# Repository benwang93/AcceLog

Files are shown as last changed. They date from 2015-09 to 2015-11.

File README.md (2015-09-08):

AcceLog - Accelerometer Log for Android
=======================================

Android
-------
This project uses the Adafruit MMA8451 breakout board connected to an Arduino Uno. The sensor and Arduino hardware can be easily modified. Eventually a custom board and enclosure should be built.

Links:
- Adafruit MMA8451 webpage:    adafru.it/2019
- Adafruit Arduino libraries:  https://learn.adafruit.com/adafruit-mma8451-accelerometer-breakout/wiring-and-test

The Arduino code and libraries are included in the Arduino folder in this repository.

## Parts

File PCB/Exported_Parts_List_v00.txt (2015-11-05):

Partlist

Exported from AcceLog_v01.sch at 11/5/2015 2:57 PM

EAGLE Version 7.3.0 Copyright (c) 1988-2015 CadSoft

Assembly variant: 

Part     Value           Device                 Package      Library             Sheet

C1       0.1uF           CAP0603-CAP            0603-CAP     SparkFun-Passives   1
C2       2.2uF           CAP_POL1206            EIA3216      SparkFun-Capacitors 1
C3       0.1uF           CAP0603-CAP            0603-CAP     SparkFun-Passives   1
C4       0.1uF           CAP0603-CAP            0603-CAP     SparkFun-Passives   1
C5       4.7uF           CAP0603-CAP            0603-CAP     SparkFun-Passives   1
C6       47pF            CAP0603-CAP            0603-CAP     SparkFun-Passives   1
C7       47pF            CAP0603-CAP            0603-CAP     SparkFun-Passives   1
C8       100nF           CAP0603-CAP            0603-CAP     SparkFun-Passives   1
C9       0.1uF           CAP0603-CAP            0603-CAP     SparkFun-Passives   1
C10      18pF            CAP0603-CAP            0603-CAP     SparkFun-Passives   1
C11      18pF            CAP0603-CAP            0603-CAP     SparkFun-Passives   1
C12      0.1uF           CAP0603-CAP            0603-CAP     SparkFun-Passives   1
C13                      CPOL-USE2-5            E2-5         rcl                 1
C15                      CPOL-USE2-5            E2-5         rcl                 1
C16                      CPOL-USE2-5            E2-5         rcl                 1
C17      0.1uF           CAP0603-CAP            0603-CAP     SparkFun-Passives   1
ICSP                     M03X22X3_SILK_MALE_PTH 2X3          SparkFun-Connectors 1
JACCEL                   M08LOCK                1X08_LOCK    SparkFun-Connectors 1
JFTDI                    M06LOCK                1X06_LOCK    SparkFun-Connectors 1
JUSB     10118193        10118193               10118193     MicroUSB            1
R1       27?             RESISTOR0603-RES       0603-RES     SparkFun-Passives   1
R2       27?             RESISTOR0603-RES       0603-RES     SparkFun-Passives   1
R3       27?             RESISTOR0603-RES       0603-RES     SparkFun-Passives   1
R4       10K?            RESISTOR0603-RES       0603-RES     SparkFun-Passives   1
R5       10K?            RESISTOR0603-RES       0603-RES     SparkFun-Passives   1
U1       MMA8452Q        MMA8452Q               QFN-16_0.5MM SparkFun-Sensors    1
U2       FTS31XS-U       FT231XS                SSOP20_L     SparkFun-DigitalIC  1
U3       ATMEGA328P_TQFP ATMEGA328P_TQFP        TQFP32-08    SparkFun-DigitalIC  1
U4       3.3V/150mA      V_REG_MIC52053.3V      SOT23-5      SparkFun-PowerIC    1
XTAL     ABLS7M2         ABLS7M2                ABLS7M2      AcceLogLib          1

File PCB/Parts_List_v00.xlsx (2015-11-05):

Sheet: Parts List
Component | Use | Description | Digikey part | Quantity | Qty Order | Price | Link
Processor | x | Atmega328P | ATMEGA328P-AU-ND | 1 | 3 | $3.58 | http://www.digikey.com/product-detail/en/ATMEGA328P-AU/ATMEGA328P-AU-ND/1832260
Oscillator | x | Small crystal | 535-12830-1-ND | 1 | 4 | $0.38 | http://www.digikey.com/product-detail/en/ABLS7M2-16.000MHZ-D-2Y-T/535-12830-1-ND/5135076
Oscillator |  | Crystal search page |  |  |  |  | http://www.digikey.com/product-search/en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
Oscillator |  | Big crystal | 535-10226-1-ND |  |  | $0.27 | http://www.digikey.com/product-detail/en/ABLS-16.000MHZ-B4-T/535-10226-1-ND/2184261
Oscillator |  | Resonator | 535-10008-1-ND |  |  | $0.38 | http://www.digikey.com/product-detail/en/AWSCR-16.00CV-T/535-10008-1-ND/2001631
Oscillator |  | MEMS oscillator | 336-2902-ND |  |  | $0.96 | http://www.digikey.com/product-detail/en/501BAA16M0000DAF/336-2902-ND/4582012
MicroUSB | x | MicroUSB jack | 609-4616-1-ND | 1 | 4 | $0.46 | http://www.digikey.com/product-detail/en/10118193-0001LF/609-4616-1-ND/2785380
Cap 0603 | x | 0.1uF | 399-1096-1-ND | 7 | 25 | $0.10 | http://www.digikey.com/product-detail/en/C0603C104K4RACTU/399-1096-1-ND/411371
Cap 0603 | x | 4.7uF | 1276-2087-1-ND | 1 | 5 | $0.10 | http://www.digikey.com/product-detail/en/CL10B475KQ8NQNC/1276-2087-1-ND/3890173
Cap 0603 | x | 47pF | 399-9083-1-ND | 2 | 10 | $0.10 | http://www.digikey.com/product-detail/en/C0603C470J3GACTU/399-9083-1-ND/3522600
Cap 0603 | x | 18pF | 399-1052-1-ND | 2 | 10 | $0.10 | http://www.digikey.com/product-detail/en/C0603C180J5GACTU/399-1052-1-ND/411327
Cap 1206 | x | 2.2uF Tantalum | 495-2228-1-ND | 1 | 5 | $0.33 | http://www.digikey.com/product-detail/en/T491A225K016ZT/495-2228-1-ND/770394
Cap 5mm | x
2x3 male hdr | x | 6 pos 2 row | 952-2121-ND | 1 | 4 | $0.23
male hdr | x | 40 pin breakaway | S1012EC-40-ND | 1 | 5 | $0.56 | http://www.digikey.com/product-detail/en/PREC040SAAN-RC/S1012EC-40-ND/2774814
male ang hdr | x | 40 pin breakaway | S1112EC-40-ND | 1 | 3 | $0.74 | http://www.digikey.com/product-detail/en/PREC040SBAN-M71RC/S1112EC-40-ND/2774894
Res 0603 | x | 27 Ohm | 311-27GRCT-ND | 3 | 15 | $0.01 | http://www.digikey.com/product-detail/en/RC0603JR-0727RL/311-27GRCT-ND/729698
Res 0603 | x | 10 kOhm | 311-10KGRCT-ND | 2 | 10 | $0.01 | http://www.digikey.com/product-detail/en/RC0603JR-0710KL/311-10KGRCT-ND/729647
Accelerometer | x | MMA8452Q | MMA8451QR1CT-ND | 1 | 3 | $1.82 | http://www.digikey.com/product-detail/en/MMA8451QR1/MMA8451QR1CT-ND/3524270
FTDI | x | FTS31XS-U | 768-1156-5-ND | 1 | 3 | $2.12 | http://www.digikey.com/product-detail/en/FT231XS-U/768-1156-5-ND/3749471
Voltage Reg | x | 3.3V/150mA | 296-35591-1-ND | 1 | 4 | $0.49 | http://www.digikey.com/product-detail/en/TLV71333PDBVR/296-35591-1-ND/3830056

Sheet: EAGLE Export
Part | Value | Device | Package | Library | Sheet
C1 | 0.1uF | CAP0603-CAP | 0603-CAP | SparkFun-Passives
C2 | 2.2uF | CAP_POL1206 | EIA3216 | SparkFun-Capacitors 1
C3 | 0.1uF | CAP0603-CAP | 0603-CAP | SparkFun-Passives 1
C4 | 100nF | CAP0603-CAP | 0603-CAP | SparkFun-Passives 1
C5 | 4.7uF | CAP0603-CAP | 0603-CAP | SparkFun-Passives 1
C6 | 47pF | CAP0603-CAP | 0603-CAP | SparkFun-Passives 1
C7 | 47pF | CAP0603-CAP | 0603-CAP | SparkFun-Passives 1
C8 | 100nF | CAP0603-CAP | 0603-CAP | SparkFun-Passives 1
C9 | 0.1uF | CAP0603-CAP | 0603-CAP | SparkFun-Passives 1
C10 | 18pF | CAP0603-CAP | 0603-CAP | SparkFun-Passives 1
C11 | 18pF | CAP0603-CAP | 0603-CAP | SparkFun-Passives 1
C12 | 100nF | CAP0603-CAP | 0603-CAP | SparkFun-Passives 1
C13 |  | CPOL-USE2-5 | E2-5 | rcl | 1
C14 |  | CPOL-USE2-5 | E2-5 | rcl | 1
C15 |  | CPOL-USE2-5 | E2-5 | rcl | 1
C16 |  | CPOL-USE2-5 | E2-5 | rcl | 1
C17 | 100nF | CAP0603-CAP | 0603-CAP | SparkFun-Passives 1
ICSP |  | M03X22X3_SILK_MALE_PTH | 2X3 | SparkFun-Connectors 1
JACCEL |  | M08LOCK | 1X08_LOCK | SparkFun-Connectors 1
JFTDI |  | M06LOCK | 1X06_LOCK | SparkFun-Connectors 1
JUSB | 10118193 | 10118193 | 10118193 | MicroUSB | 1
R1 | 27? | RESISTOR0603-RES | 0603-RES | SparkFun-Passives 1
R2 | 27? | RESISTOR0603-RES | 0603-RES | SparkFun-Passives 1
R3 | 27? | RESISTOR0603-RES | 0603-RES | SparkFun-Passives 1
R4 | 10K? | RESISTOR0603-RES | 0603-RES | SparkFun-Passives 1
R5 | 10K? | RESISTOR0603-RES | 0603-RES | SparkFun-Passives 1
U1 | MMA8452Q | MMA8452Q | QFN-16_0.5MM SparkFun-Sensors | 1
U2 | FTS31XS-U | FT231XS | SSOP20_L | SparkFun-DigitalIC 1
U3 | ATMEGA328P_TQFP | ATMEGA328P_TQFP | TQFP32-08 | SparkFun-DigitalIC 1
U4 | 3.3V/150mA | V_REG_MIC52053.3V | SOT23-5 | SparkFun-PowerIC | 1
XTAL | ABLS7M2 | ABLS7M2 | ABLS7M2 | AcceLogLib | 1

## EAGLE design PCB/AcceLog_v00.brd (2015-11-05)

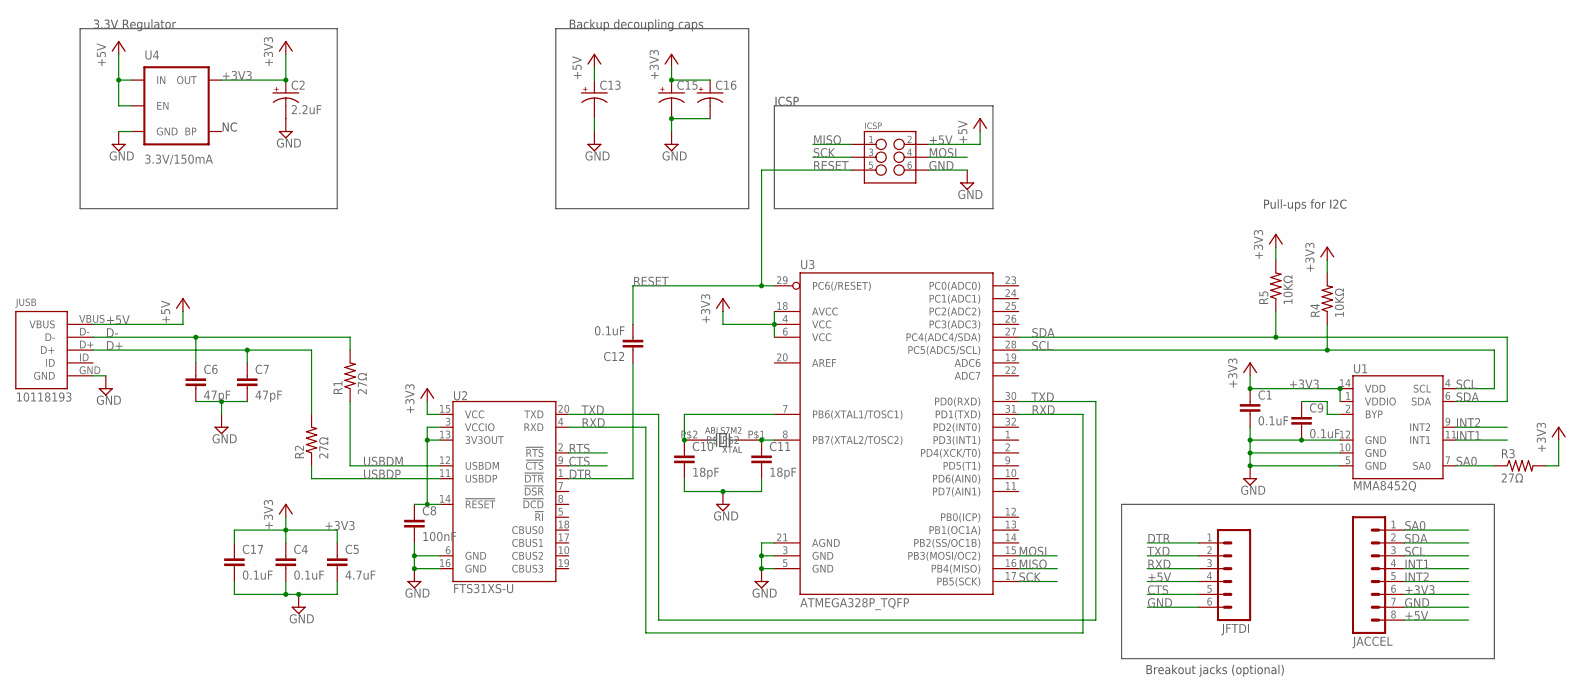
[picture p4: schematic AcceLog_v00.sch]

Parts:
C1, C4, C9, C12, C17: 0.1uF; 0603-CAP
C2: 2.2uF; EIA3216
C5: 4.7uF; 0603-CAP
C6, C7: 47pF; 0603-CAP
C8: 100nF; 0603-CAP
C10, C11: 18pF; 0603-CAP
C13, C15, C16: CPOL-USE2-5; E2-5
ICSP: M03X22X3_SILK_MALE_PTH; 2X3
JACCEL: M08LOCK; 1X08_LOCK
JFTDI: M06LOCK; 1X06_LOCK
JUSB: 10118193
R1, R2, R3: 27Ω; 0603-RES
R4, R5: 10KΩ; 0603-RES
U1: MMA8452Q; QFN-16_0.5MM
U2: FTS31XS-U; SSOP20_L
U3: ATMEGA328P_TQFP; TQFP32-08
U4: 3.3V/150mA; SOT23-5
XTAL: ABLS7M2

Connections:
+3V3: C1.1, C2.A (+), C4.1, C5.1, C15.+, C16.+, C17.1, JACCEL.6, R3.2, R4.2, R5.2, U1.1 (VDDIO), U1.14 (VDD), U2.15 (VCC), U3.4 (VCC), U3.6 (VCC), U3.18 (AVCC), U4.5 (OUT)
+5V: C13.+, ICSP.2, JACCEL.8, JFTDI.4, JUSB.VBUS, U4.1 (IN), U4.3 (EN)
CTS: JFTDI.5, U2.9 (!CTS)
D+: C7.1, JUSB.D+, R2.2
D-: C6.1, JUSB.D-, R1.2
DTR: C12.1, JFTDI.1, U2.1 (!DTR)
FTDI3V3: C8.1, U2.3 (VCCIO), U2.13 (3V3OUT), U2.14 (!RESET)
GND: C1.2, C2.C (-), C4.2, C5.2, C6.2, C7.2, C8.2, C9.2, C10.2, C11.2, C13.-, C15.-, C16.-, C17.2, ICSP.6, JACCEL.7, JFTDI.6, JUSB.GND, U1.5 (GND), U1.10 (GND), U1.12 (GND), U2.6 (GND), U2.16 (GND), U3.3 (GND), U3.5 (GND), U3.21 (AGND), U4.2 (GND)
INT1: JACCEL.4, U1.11 (INT1)
INT2: JACCEL.5, U1.9 (INT2)
MISO: ICSP.1, U3.16 (PB4(MISO))
MOSI: ICSP.4, U3.15 (PB3(MOSI/OC2))
unnamed: C10.1, U3.7 (PB6(XTAL1/TOSC1)), XTAL.P$2
unnamed: C9.1, U1.2 (BYP)
unnamed: C11.1, U3.8 (PB7(XTAL2/TOSC2)), XTAL.P$1
RESET: C12.2, ICSP.5, U3.29 (PC6(/RESET))
RTS: U2.2 (!RTS)
RXD: JFTDI.3, U2.4 (RXD), U3.31 (PD1(TXD))
SA0: JACCEL.1, R3.1, U1.7 (SA0)
SCK: ICSP.3, U3.17 (PB5(SCK))
SCL: JACCEL.3, R4.1, U1.4 (SCL), U3.28 (PC5(ADC5/SCL))
SDA: JACCEL.2, R5.1, U1.6 (SDA), U3.27 (PC4(ADC4/SDA))
TXD: JFTDI.2, U2.20 (TXD), U3.30 (PD0(RXD))
USBDM: R1.1, U2.12 (USBDM)
USBDP: R2.1, U2.11 (USBDP)

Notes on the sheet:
3.3V Regulator
Pull-ups for I2C
ICSP
Backup decoupling caps
Breakout jacks (optional)

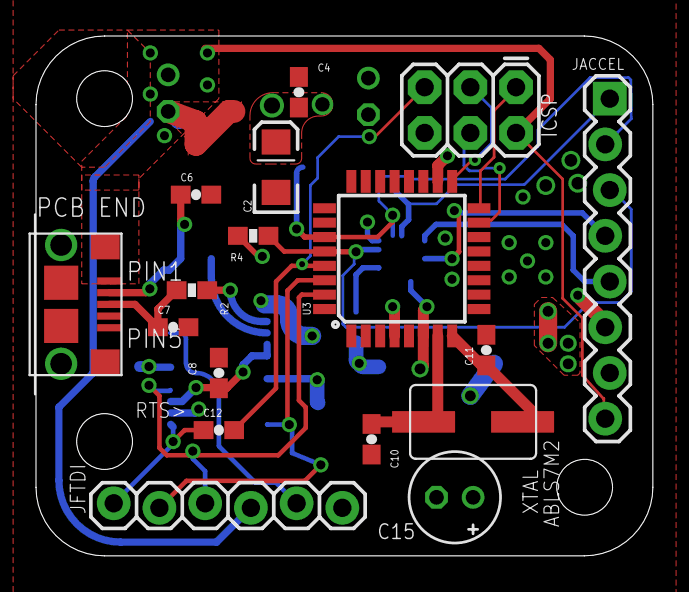
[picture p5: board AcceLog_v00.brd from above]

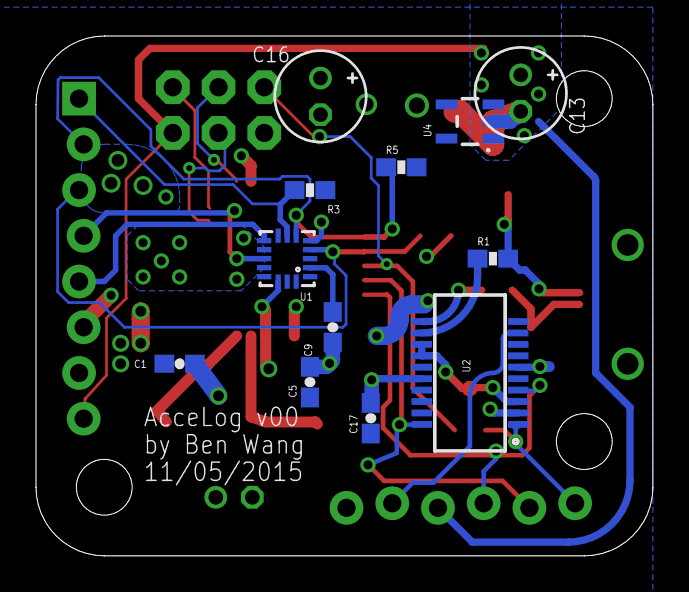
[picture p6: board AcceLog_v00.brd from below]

Board: 2 copper layers, 34.3 x 28.9 mm, 29 parts (12 on the bottom side), 24 nets.

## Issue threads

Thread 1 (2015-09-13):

Increase baud rate from 9600 to 115200

benwang93, 2015-09-13:

benwang93, 2015-09-17:
Found out that the getLineEncoding() function in AndroidSerialMonitor just sends the baud rate encoded as hex to the Arduino pseudo-FTDI. Upped the baud rate to 115200, but now phone crashes very quickly. Decreased it to 19200, but it still crashes quick.

Determined the app is not crashing from the graph by plotting only 1/100 data points

benwang93, 2015-09-24:
After implementing delete on old points (>120 points) on graph, app runs longer now.

115200 is a bit high with the current scheme - app crashes within a minute. At least need to improve data efficiency.

19200 works well, at least for 10+ minutes.

benwang93, 2015-10-02:
Implemented new serial packet structure, where binary data is now sent in the form of:
  [SOP][time in millis (int)][accel x (float)][accel y (float)][accel z (float)]

This takes 6.25ms to send 1 packet (15*(1/19200)*1000*8)ms, and we are getting ~9ms between samples. Arduino is programmed with a 100us delay between each packet.

Next: Try increasing baud rate to 115200. Should yield a theoretical data transfer time of (15*(1/115200)*1000*8) = 1.0416666666667ms

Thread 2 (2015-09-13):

App crashes within the first few seconds of starting logging

benwang93, 2015-09-13:
This may be associated with the console. Perhaps start by trying to disable the console prints

benwang93, 2015-10-02:
Added exception checking. Error was with incorrectly parsed packet. Newest implementation doesn't support old string packet structure/parsing anyway.

Closed 2015-10-02.

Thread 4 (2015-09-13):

Endurance test

benwang93, 2015-09-13:
Investigate effects on app speed over time.

1. Start with disabling console print
2. Try saving in background task to not slow down UI thread
3. If still slow, try saving periodically and clearing data from memory in background task. Maybe have 2 arrays, and swap/save them every so often

benwang93, 2015-09-13:
If chart is bogging down, can just plot a few times per second, or delete points older than a certain amount of time

benwang93, 2015-09-15:
Status improved by not logging data in console. After rooting phone, able to identify runtime errors. One instance is a malformed double. Try using a try-catch

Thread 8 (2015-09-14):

Notification center & Serial Monitor mode

benwang93, 2015-09-14:
Add textview or scrolling listview at top set to wrap_content layout_height, and add notifications there, with a task scheduled several seconds after to delete them.

The present serial monitor can be hidden until enabled, for debug mode. Don't print to it unless active, to prevent memory from clogging up.

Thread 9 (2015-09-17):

PCB Design

benwang93, 2015-09-17:
1) Spec major components (proc, FTDI, accelerometer)
2) Spec support components (passives/oscillator, voltage regulator?)
3) Schematic
4) PCB v0
5) Order parts

benwang93, 2015-10-02:
Case idea: (laser) cut 2 acryllic panels, sandwich PCB w/ spacers, seal edges w/ caulk/hot glue.

Previously, tried to test test/program with FTDI board, using a 10uF(?), but failed. Need to try this again and/or put oscope on pins and see what's happening to the signal.

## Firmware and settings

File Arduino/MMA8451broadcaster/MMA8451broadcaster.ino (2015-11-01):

/**************************************************************************/
/*!
    @file     Adafruit_MMA8451.h
    @author   K. Townsend (Adafruit Industries)
    @license  BSD (see license.txt)

    This is an example for the Adafruit MMA8451 Accel breakout board
    ----> https://www.adafruit.com/products/2019

    Adafruit invests time and resources providing this open source code,
    please support Adafruit and open-source hardware by purchasing
    products from Adafruit!

    @section  HISTORY

    v1.0  - First release
*/
/**************************************************************************/

#include <Wire.h>
#include <Adafruit_MMA8451.h>
#include <Adafruit_Sensor.h>

// Packet definitions
const char PACKET_START = '{';
const char PACKET_END   = '}';
const char PACKET_DELIM = '\t';

const char PACKET_TYPE_ACCEL_G = 'G';

const unsigned int BAUD_RATE = 57600;

// Delay between samples
const int SAMPLE_PERIOD_US = 0; // us


// Accelerometer object
Adafruit_MMA8451 mma = Adafruit_MMA8451();

void setup(void) {
  Serial.begin(BAUD_RATE);
  
  Serial.println("Adafruit MMA8451 test!");
  

  if (! mma.begin()) {
    Serial.println("Couldnt start");
    while (1);
  }
  Serial.println("MMA8451 found!");
  
  mma.setRange(MMA8451_RANGE_2_G);
  
  Serial.print("Range = "); Serial.print(2 << mma.getRange());  
  Serial.println("G");
  
}

void loop() {
  // Read the 'raw' data in 14-bit counts
  mma.read();
  unsigned long currTime = millis();
  
  // Send packet
//  Serial.print(PACKET_START); Serial.print(PACKET_TYPE_ACCEL_G); Serial.print(PACKET_DELIM); Serial.print(mma.x_g); Serial.print(PACKET_DELIM); Serial.print(mma.y_g); Serial.print(PACKET_DELIM); Serial.print(mma.z_g); Serial.println(PACKET_END);
  Serial.print(PACKET_START); /*Serial.print(PACKET_TYPE_ACCEL_G);*/ Serial.write((byte*) &currTime, sizeof(unsigned long)); Serial.write((byte*) &mma.x_g, sizeof(float)); Serial.write((byte*) &mma.y_g, sizeof(float)); Serial.write((byte*) &mma.z_g, sizeof(float));

  // Delay to not flood Android device
  delayMicroseconds(SAMPLE_PERIOD_US);
}

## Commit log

2015-09-08 included Arduino code
2015-09-11 Working CSV save feature. disabled some debug print in console
2015-09-11 working graphical log, but app crashes seconds in...
    [AcceLog_out.csv, Sample analysis.xlsx]
2015-09-14 Start/Stop button functional, surpresses keyboard on start
2015-09-15 added debug view toggle button
2015-09-15 changed baud rate 9600 to 115200. app crashes now from too much data... in graph maybe
    [MMA8451broadcaster.ino]
2015-09-18 started PCB design
    [AcceLog_v01.brd, AcceLog_v01.sch]
2015-09-19 worked on board more
    [AcceLog_v01.brd, AcceLog_v01.sch]
2015-09-23 ability to keep N most recent points. doesn't crash after over 10 min now with higher baud rate
    [MMA8451broadcaster.ino]
2015-09-23 milliseconds shown in graph, frame skip, 19200 baud
    [MMA8451broadcaster.ino]
2015-10-02 updated backend for binary data transfer, 19200 baud, eliminate packet type, add sample period TODO: add timestamp/deltaT to packet
2015-10-02 timestamp from Arduino now, will work up to 25 days of recording. Millis save in .csv too
2015-10-03 upped baud rate to 57600, bc 115200 crashes phone. added data analysis
    [AcceLog_out_2015102-233553-ANALYSIS.xlsx]
2015-10-03 updated analysis with frequency and file size analysis
    [AcceLog_out_2015102-233553-ANALYSIS.xlsx]
2015-10-28 Added ability to set frameskip at runtime
2015-10-28 updated frameskip dev UI
2015-11-04 initial schematic, working on initial board
    [AcceLog_v01.brd, AcceLog_v01.sch, Parts_List_v00.xlsx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]
2015-11-04 initial board routed
    [AcceLog_v01.brd, AcceLog_v01.sch]
2015-11-05 AcceLog_v00 Order Placed
    [AcceLog_v00.brd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]

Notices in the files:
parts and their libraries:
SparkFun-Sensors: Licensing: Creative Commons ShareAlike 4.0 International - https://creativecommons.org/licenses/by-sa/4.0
